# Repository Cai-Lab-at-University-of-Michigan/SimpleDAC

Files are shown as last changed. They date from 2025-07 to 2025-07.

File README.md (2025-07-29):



# SimpleDAC
An open source hardware interface for experimental automation

## Project Layout

This repository is split into two folders:

- [/PCB](/PCB/) contains the KiCAD files used to produce the PCB.
- [/Examples](/Examples/) contains code examples for SimpleDAC firmware.
- [/Caddy](/Caddy/) contains the 3D modeling files for the SimpleDAC case.

## Building code examples
All code examples are provided with example CMake files. These can be built by following the [Pico SDK](https://github.com/raspberrypi/pico-sdk) install and build instructions.

## Citation

If this project is useful for your applications, please cite the preprint:
Walker, Logan A., et al. “A Low-Cost and Robust Microscope Hardware Trigger Interface Board.” OSF Preprints, Jan. 2023, https://doi.org/10.31219/osf.io/fcb3t.

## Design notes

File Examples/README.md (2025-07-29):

# Code Examples

| Demo Name | Folder Path | Description |
|---|---|---|
| micromanager | Examples/micromanager | Enables control of  |
| Triggered Function Generator | Examples/triggered_function_generator | Generates different waveforms, with or without triggering |
| Serial Function Generator  | Examples/serial_function_generator | Allows user input to control DAC through a serial connection |

## Building Code Examples

A file, `build.sh` is included with each code example which uses [https://github.com/lukstep/raspberry-pi-pico-docker-sdk](lukstep/raspberry-pi-pico-docker-sdk) to build the example code inside of Docker:
`# sh build.sh`

Alternatively, these source files can be built using the Raspberry Pi Pico SDK, installed manually.

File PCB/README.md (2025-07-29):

# PCB

In this folder you will find the KiCAD schematics used to produce the SimpleDAC PCB.
The `.kicad_pcb` file can be directly uploaded to a service such as [OshPark](https://oshpark.com/) for printing.
These files were designed with KiCAD 8.

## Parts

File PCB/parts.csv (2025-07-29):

Designator(s) | Component | # | Each | Total | Source and Part Number | URL
OPA188 | TI OPA188 | 2 | $1.91 | $3.82 | DigiKey | OPA188AIDR | https://www.digikey.com/en/products/detail/texas-instruments/OPA188AIDR/4135406
DAC8560 | TI DAC8560 | 2 | $8.04 | $16.08 | DigiKey | DAC8560ICDGKT | https://www.digikey.com/en/products/detail/texas-instruments/DAC8560ICDGKT/1278908
C_LOAD | C_COMP | 100pF Film Capacitor | 4 | $1.30 | $5.20 | DigiKey | C322C101F1G5TA | https://www.digikey.com/en/products/detail/kemet/C322C101F1G5TA/3725991
R_G1 | 11KΩ Resistor 0.1% | 2 | $1.19 | $2.38 | DigiKey | YR1B11KCC | https://www.digikey.com/en/products/detail/te-connectivity-passive-product/YR1B11KCC/2390691
R_G2 | 8.25KΩ Resistor 0.1% | 2 | $0.82 | $1.64 | DigiKey | YR1B8K25CC | https://www.digikey.com/en/products/detail/te-connectivity-passive-product/YR1B8K25CC/2390957
R_FB | 33KΩ Resistor 0.1% | 2 | $0.60 | $1.20 | DigiKey | MFP-25BRD52-33K | https://www.digikey.com/en/products/detail/yageo/MFP-25BRD52-33K/2058815
R_ISO | 10KΩ Resistor 0.1% | 2 | $0.60 | $1.20 | DigiKey | 10KADCT-ND | https://www.digikey.com/en/products/detail/yageo/MFP-25BRD52-10K/2058797
R_SPLIT | 10KΩ Resistor 0.1% | 2 | $0.60 | $1.20 | DigiKey | 10KADCT-ND | https://www.digikey.com/en/products/detail/yageo/MFP-25BRD52-10K/2058797
R_DATA | 12Ω Resistor 1% | 2 | $0.10 | $0.20 | DigiKey | MF0207FTE52-12R | https://www.digikey.com/en/products/detail/yageo/MF0207FTE52-12R/9125395
GPxx and DACx | BNC Connector | 6 | $2.06 | $12.36 | DigiKey | CONBNC002 | https://www.digikey.com/en/products/detail/te-connectivity-linx/CONBNC002/16013841
PWR | Banana Receptacle | 3 | $2.55 | $7.65 | DigiKey | CT3151SP-2 | https://www.digikey.com/en/products/detail/cal-test-electronics/CT3151SP-2/6005547
Header Connector | Header Connector | 2 | $1.10 | $2.20 | DigiKey | PPTC201LFBN-RC | https://www.digikey.com/en/products/detail/sullins-connector-solutions/PPTC201LFBN-RC/810158
Headers | Headers | 2 | $1.10 | $2.20 | DigiKey | 61302011121 | https://www.digikey.com/en/products/detail/w%C3%BCrth-elektronik/61302011121/4846860
Raspberry Pi 2 | Raspberry Pi Pico 2 | 1 | $5.00 | $5.00 | DigiKey | SC1631 | https://www.digikey.com/en/product-highlight/r/raspberry-pi/raspberry-pi-sc1631-pico-2
PCB | This Work (Fig. board_raw) | 1 | $12.63 | $12.63 | OshPark | custom

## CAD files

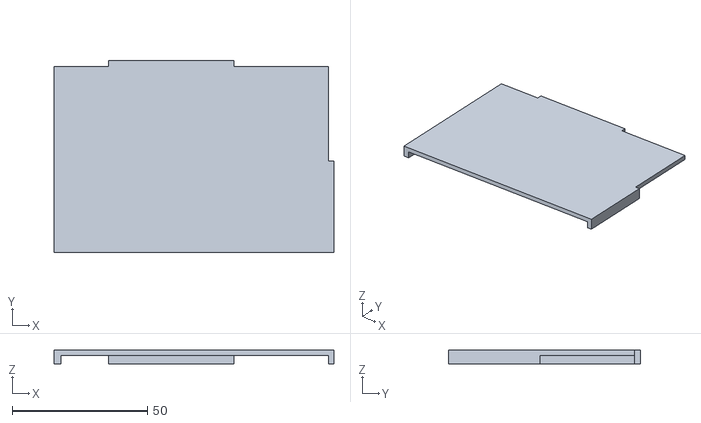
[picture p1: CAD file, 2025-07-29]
Caddy/simpledac_caddy_top.stl
103.7 x 71.3 x 5.00

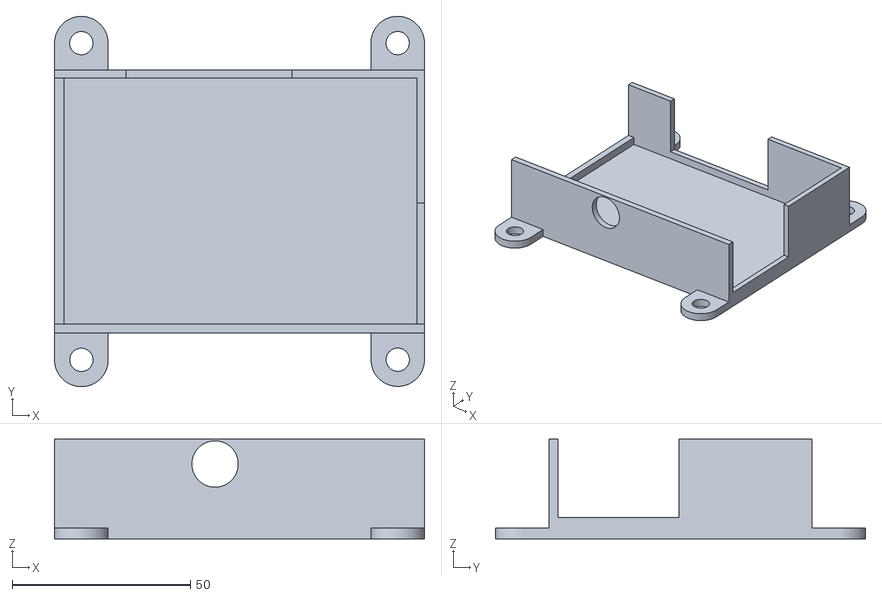
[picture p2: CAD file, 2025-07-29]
Caddy/simpledac_caddy_bottom.stl
103.7 x 103.8 x 28.0

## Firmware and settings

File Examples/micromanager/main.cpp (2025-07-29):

#include <stdio.h>
#include "pico/stdlib.h"

#include "simpledac.hpp"

unsigned int version = 2;

const size_t output_pin_count = 4;
const int output_pins[output_pin_count] = {22, 26, 27, 28};
char current_output_pattern = 0;

void write_outputs()
{
    for (int i = 0; i < output_pin_count; i++)
    {
        const uint8_t id = output_pins[i];
        const bool val = ((current_output_pattern >> i) & 1) != 0;
        gpio_put(id, val);
    }
}

int main()
{
    stdio_init_all();

    initialize_simpledac();
    set_value_simpledac(0, 32768);
    set_value_simpledac(1, 32768);

    for (size_t i = 0; i < output_pin_count; i++)
    {
        // Initialize Input Pin
        gpio_init(output_pins[i]);
        gpio_set_dir(output_pins[i], GPIO_OUT);
        gpio_put(output_pins[i], 0);
    }

    int channel;
    char msb, lsb;
    uint16_t towrite;

    // Loop forever
    while (1)
    {
        int in_int = PICO_ERROR_TIMEOUT;

        do
        {
            in_int = getchar_timeout_us(10000); // 10ms
        } while (in_int == PICO_ERROR_TIMEOUT);

        char in_byte = (char)in_int;

        switch (in_byte)
        {
        case 0:
            break;

        case 1:
            current_output_pattern = getchar();
            write_outputs();
            printf("%c", (char)in_byte);
            break;

        case 2:
            printf("%c", (char)in_byte);
            printf("%c", (char)current_output_pattern);
            break;

        case 3:
            channel = getchar();
            msb = getchar();
            lsb = getchar();

            towrite = ((uint16_t)(((uint8_t)msb) << 8)) | (uint8_t)lsb;
            towrite <<= (16 - 12); // Micromanager puts out 12 bit numbers

            set_value_simpledac((int)channel, towrite);

            printf("%c", (char)in_byte);
            printf("%c", (char)channel);
            printf("%c", msb);
            printf("%c", lsb);
            break;
        case 5:
            break;
        case 6:
            break;
        case 7:
        case 30:
            printf("MM-Ard\n");
            break;
        case 31:
            printf("%d\n", version);
            break;
        case 40:
            printf("%d", 40);
            printf(0);
            break;
        case 41:
            break;
        case 42:
            break;
        }
    }

    return 0;
}

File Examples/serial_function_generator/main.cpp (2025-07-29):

#include <stdio.h>
#include <stdlib.h>
#include <string.h>
#include <math.h>

#include "pico/stdlib.h"

#include "simpledac.hpp"


// USB COM Libraries
#include <tusb.h>

#define INPUT_BUFFER_SIZE 32

int main()
{
    stdio_init_all();

    initialize_simpledac();

    char buffer[INPUT_BUFFER_SIZE];
    int index = 0;

    while (true)
    {
        int c = getchar_timeout_us(0); // non-blocking
        if (c == PICO_ERROR_TIMEOUT)
        {
            sleep_ms(10); // avoid tight loop
            continue;
        }

        if (c == '\n' || c == '\r')
        {
            buffer[index] = '\0';

            // Parse as integer
            int value = atoi(buffer);
            printf("Received number: %d\n", value);

            set_value_simpledac(0, value);
            set_value_simpledac(1, value);

            // Reset buffer
            index = 0;
            memset(buffer, 0, INPUT_BUFFER_SIZE);
        }
        else if (index < INPUT_BUFFER_SIZE - 1)
        {
            buffer[index++] = (char)c;
        }
    }

    return 0;
}

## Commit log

2024-05-06 Adding PCBs
    [OffboardDAC.kicad_pcb, OffboardDAC.sch]
2024-05-06 Switch pico to import
2025-06-09 Update PCB design
    [OffboardDAC.kicad_pcb, OffboardDAC.sch, SimpleDAC.kicad_pcb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]
2025-06-18 Update PCB
    [SimpleDAC.kicad_pcb]
2025-06-24 Revert changes to function generator
    [main.cpp]
2025-07-03 Updating schematic
    [SimpleDAC.kicad_pcb, SimpleDAC.kicad_sch]
2025-07-29 Add caddy files
    [simpledac_caddy_bottom.stl, simpledac_caddy_top.stl]
